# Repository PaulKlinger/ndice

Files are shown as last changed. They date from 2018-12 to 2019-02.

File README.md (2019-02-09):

# Compact Universal Electronic Dice

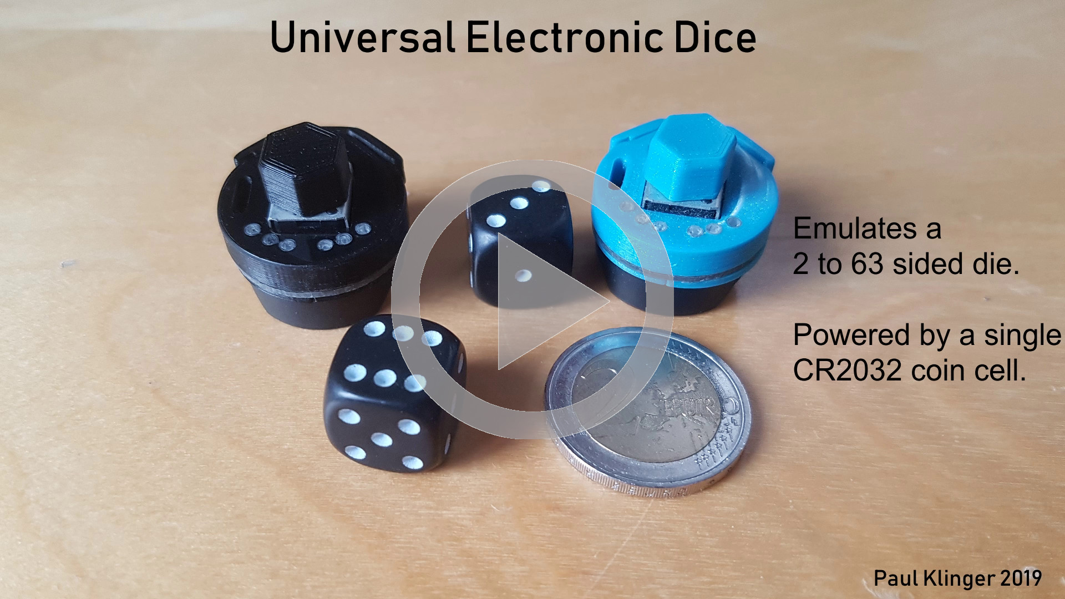
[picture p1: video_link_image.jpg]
(https://youtu.be/G88BLo7Vowo "Project video")


Some hints for anyone trying to build these:

- The PCB should be 0.8mm thick.

- You might have noticed that the two parts of the 3D printed top part that press on the buttons are not symmetric. That's because the smd buttons have a little play on when put into the alignment holes in the PCB (I think the holes on my boards were drilled slightly oversized). I happened to solder the left button a little further in than the right one, and designed the case around that (very professional, I know...).

- The holes over the LEDs in the top cover are filled with some 2mm PMMA fiber optic cable. I bought it [here](https://www.aliexpress.com/item/5mX-Transparent-side-glow-plastic-PMMA-fiber-optic-cable-solid-core-optic-cable-diameter-2mm-3mm/32807597828.html). This kind of fiber is not optimal for this because it glows from the side (which I needed for [this project](https://github.com/PaulKlinger/kerr_geodesic_sculpture)), but most of the light still comes out the end. Getting the fiber into the holes can be kind of tricky, depending on the precise over-/underextrusion of your 3D printer & filament (for me it was a lot easier with the blue than the black ones). I cut the tip of the fiber to a point, push it firmly through so a bit sticks out the other side, and then use pliers to pull it all the way through. Then I cut it flush using some flush cutters. The pliers and cutters invariable leave some scratches so I have to polish the top...

- To get the (3D printed) cap on the potentiometer you need to cut off the top of the knob. The ones mentioned in the BOM have a relatively soft plastic knob, so that's pretty easy. The cap should be a friction fit.

- The battery holder is soldered to the bottom, so that the MCU sits between the bottom of the battery holder and the PCB (the pins should be long enough to still reach through the PCB). Make sure that the battery holder is parallel to the PCB.

- The 3D printed spacers go between the battery holder and the PCB. I glued them to the PCB with superglue. They are mostly there to hide the gap and don't really provide mechanical support.

- The 3D printed top sort of holds in place without glue, but to make sure it sticks I superglued it to the side of the potentiometer by pressing it forward (towards the buttons) and down. This way it can still be removed by pressing in the opposite direction to break the glue.

- The oval hole on the left side of the top cover is used to reprogram the MCU without dissasembling the die. I use a small jig with three spring loaded pogo pins ([bought here](https://www.aliexpress.com/item/50pcs-set-New-P75-B1-Dia-1-02mm-100g-Cusp-Spear-Spring-Loaded-Test-Probes-Pogo/32767984398.html)) to connect to the pads underneath (you need to put some solder in the three holes to make a surface for the pins to push against). The holes are the standard pin header ones, 0.1 inch apart, so you can just solder the pogo pins into three adjacent holes of a protoboard. From the buttons down the three pads are VCC, UPDI data, GND. Here's [a picture](programming_jig.jpg) of the programming jig with a PICkit 4 connected (the PICkit doesn't provide power, so that comes from the usb). (I don't really recommend the pickit, the AVR support is still in beta and there are some irritating bugs.)

I bought all the components except the [ATtiny1614 microcontroller](https://octopart.com/attiny1614-ssfr-microchip-82181131) from Aliexpress. They are, e.g., available here (no guarantee that the links still work):
- [Capacitors (x100) - $1.94](https://www.aliexpress.com/item/100pcs-3-3PF-47UF-0805-SMD-100V-X7R-10-100nf-0-1uf-104K-104-22UF-4/32882102243.html)
- [Resistors (x100) - $0.63](https://www.aliexpress.com/item/100Pcs-0805-SMD-1-4W-0R-10M-chip-resistor-0-10R-100R-220R-330R-470R-1K/32858225842.html)
- [Potentiometers (x10) - $1.41](https://www.aliexpress.com/item/10pcs-x-RV09-vertical-12-5mm-Shaft-5K-10K-50K-100K-0932-Adjustable-Resistor-9-type/32897258726.html)
- [Battery holder (x10) - $0.65](https://www.aliexpress.com/item/10PCS-Battery-Button-Cell-Holder-Socket-Case-CR2032-battery-holder-2032/32819924096.html)
- [LEDs (x100) - $0.55](https://www.aliexpress.com/item/Free-Ship-100PCS-0805-light-emitting-diode-SMD-LED-bead-Red-Yellow-Green-White-Blue-Orange/32871959868.html)
- [switch (x100) - $1.43](https://www.aliexpress.com/item/50pcs-3-6mm-SMD-light-touch-switch-2-pin-side-button-Micro-switch-button-switches-3mm/32311331185.html)

(everything including shipping to Austria)

That's < $0.9 / unit for everything except the microcontroller when building 10 units, and < $1.55 / unit total. (And you have a lot of components left over after building 10, like 80 switches, 40 LEDs, 90 capacitors,...)

If the links above don't work, or you want to buy from more reputable suppliers, check the [octopart bom](pcb/octopart_bom.md).

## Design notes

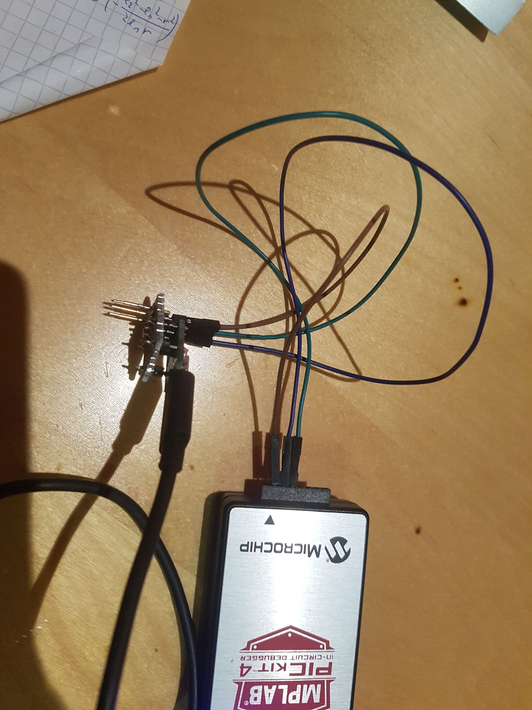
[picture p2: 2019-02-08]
programming_jig.jpg

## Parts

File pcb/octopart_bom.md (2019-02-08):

Qty | Line Item | Manufacturer | MPN | Octopart URL | Schematic Reference | Internal Part Number | Description | Total Qty (@ Batch Size: 1) | SKU | SKU | Packaging | Packaging | Unit Price (@ Batch Size: 1) | Unit Price (@ Batch Size: 1) | In Stock | In Stock | MOQ | MOQ | URL | URL | Distributor [Lowest Price (Overall)] | SKU [Lowest Price (Overall)] | Packaging [Lowest Price (Overall)] | Unit Price (@ Batch Size: 1) [Lowest Price   (Overall)] | Line Total [Lowest Price (Overall)] | Batch Total [Lowest Price (Overall)] | In Stock [Lowest Price (Overall)] | MOQ [Lowest Price (Overall)] | URL [Lowest Price (Overall)] | Notes
-- | -- | -- | -- | -- | -- | -- | -- | -- | -- | -- | -- | -- | -- | -- | -- | -- | -- | -- | -- | -- | -- | -- | -- | -- | -- | -- | -- | -- | -- | --
  |   |   |   |   |   |   |   |   | Digi-Key | Mouser | Digi-Key | Mouser | Digi-Key | Mouser | Digi-Key | Mouser | Digi-Key | Mouser | Digi-Key | Mouser |   |   |   |   |   |   |   |   |   |  
1 | ATTINY1614-SSFR | Microchip | ATTINY1614-SSFR | https://octopart.com/attiny1614-ssfr-microchip-82181131 | 1 | ATTINY1614-SSFRCT-ND | ATTINY1614-SSFR | Cut Tape | 0.75 | 0.75 | 4187 | 4507 | 1 | 1 | https://octopart.com/click/track?ak=39ac400e&sig=0a83d4a&sid=459&ppid=82181131&vpid=431492422&ct=offers | https://octopart.com/click/track?ak=39ac400e&sig=014fdb8&sid=2401&ppid=82181131&vpid=447257214&ct=offers | Arrow Electronics, Inc. | ATTINY1614-SSFR | Cut Tape | 0.7314 | 0.7314 | 0.7314 | 2771 | 1 | https://octopart.com/click/track?ak=39ac400e&sig=05768f2&sid=1106&ppid=82181131&vpid=473294420&ct=offers
1 | GRM21BR61C106KE15L | Murata | GRM21BR61C106KE15L | https://octopart.com/grm21br61c106ke15l-murata-197438 | 1 | 490-3886-1-ND | GRM21BR61C106KE15L | Cut Tape | 0.32 | 0.36 | 5E+06 | 1E+06 | 1 | 1 | https://octopart.com/click/track?ak=39ac400e&sig=0d5de69&sid=459&ppid=197438&vpid=1827596&ct=offers | https://octopart.com/click/track?ak=39ac400e&sig=0187e19&sid=2401&ppid=197438&vpid=38925211&ct=offers | Conrad | 450891 |   | 0.1585 | 0.1585 | 0.1585 | 3263 |   | https://octopart.com/click/track?ak=39ac400e&sig=0ed9acd&sid=14587&ppid=197438&vpid=410932726&ct=offers
1 | A18081100UX0281 | Unique Bargains | A18081100UX0281 | https://octopart.com/a18081100ux0281-unique+bargains-97182774 | 1 |   |   |   |   |   |   |   |   |   |   |   |   | Newegg Business | 9SIV0KK8DW7406 | 5.93 | 5.93 | 5.93 | -2 |   | https://octopart.com/click/track?ak=39ac400e&sig=07dd695&sid=27355&ppid=97182774&vpid=510745618&ct=offers
1 | PTV09A-4020F-B103 | Bourns | PTV09A-4020F-B103 | https://octopart.com/ptv09a-4020f-b103-bourns-1677656 | 1 | PTV09A-4020F-B103-ND | PTV09A-4020F-B103 | Tray | Bulk | 0.83 | 0.74 | 1329 | 815 | 1 | 1 | https://octopart.com/click/track?ak=39ac400e&sig=0dda3a8&sid=459&ppid=1677656&vpid=54316735&ct=offers | https://octopart.com/click/track?ak=39ac400e&sig=0e6202d&sid=2401&ppid=1677656&vpid=37823497&ct=offers | Newark | 10C0389 | 0.666 | 0.666 | 0.666 | 311 | 1 | https://octopart.com/click/track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
6 | KP-2012SYC | Kingbright | KP-2012SYC | https://octopart.com/kp-2012syc-kingbright-7381223 | 6 |   |   |   |   |   |   |   |   |   |   |   |   | TME | KP-2012SYC | 0.1305 | 0.7828 | 0.7828 | 16545 | 5 | https://octopart.com/click/track?ak=39ac400e&sig=0e786ef&sid=1532&ppid=7381223&vpid=88625567&ct=offers
6 | CR0805-JW-103ELF | Bourns | CR0805-JW-103ELF | https://octopart.com/cr0805-jw-103elf-bourns-975882 | 6 | CR0805-JW-103ELFCT-ND | CR0805-JW-103ELF | Cut Tape | 0.1 | 0.1 | 352715 | 0 | 1 | 1 | https://octopart.com/click/track?ak=39ac400e&sig=0185210&sid=459&ppid=975882&vpid=54325049&ct=offers | https://octopart.com/click/track?c=1&ak=39ac400e&sig=01cc0e2&sid=2401&ppid=975882&vpid=37710188&ct=offers | Avnet | 02J2519 | 0.006 | 0.036 | 0.036 | 0 | 1 | https://octopart.com/click/track?c=1&ak=39ac400e&sig=0721438&sid=5822&ppid=975882&vpid=503034749&ct=offers
1 | BS-7 | Memory Protection Devices | BS-7 | https://octopart.com/bs-7-memory+protection+devices-29784142 | 1 | BS-7-ND | Bulk |   | 0.75 |   | 23822 |   | 1 |   | https://octopart.com/click/track?ak=39ac400e&sig=0f913ab&sid=459&ppid=29784142&vpid=1941628&ct=offers | Onlinecomponents.com | BS-7 |   | 0.73 | 0.73 | 0.73 | 1361 | 1 | https://octopart.com/click/track?ak=39ac400e&sig=0dbb6e0&sid=2429&ppid=29784142&vpid=446090856&ct=offers

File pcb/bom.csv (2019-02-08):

Manufacturer Part Number | Description | Quantity | Purchase Link (example)
ATTINY1614-SSFR | MCU | 1 | https://octopart.com/attiny1614-ssfr-microchip-82181131
K2-1112SA-A4SW-01 | smd side switch | 2 | https://www.aliexpress.com/item/50pcs-3-6mm-SMD-light-touch-switch-2-pin-side-button-Micro-switch-button-switches-3mm/32311331185.html
 | 0805 10K smd resistor | 6 | https://www.aliexpress.com/item/100Pcs-0805-SMD-1-4W-0R-10M-chip-resistor-0-10R-100R-220R-330R-470R-1K/32858225842.html
 | 0805 10uf smd ceramic cap | 1 | https://www.aliexpress.com/item/100pcs-3-3PF-47UF-0805-SMD-100V-X7R-10-100nf-0-1uf-104K-104-22UF-4/32882102243.html
 | 0805 yellow smd LED | 6 | https://www.aliexpress.com/item/Free-Ship-100PCS-0805-light-emitting-diode-SMD-LED-bead-Red-Yellow-Green-White-Blue-Orange/32871959868.html
RV09 B100K B104 | 100K potentiometer 12.5mm through hole | 1 | https://www.aliexpress.com/item/10pcs-x-RV09-vertical-12-5mm-Shaft-5K-10K-50K-100K-0932-Adjustable-Resistor-9-type/32897258726.html
 | CR2032 battery holder | 1 | https://www.aliexpress.com/item/10PCS-Battery-Button-Cell-Holder-Socket-Case-CR2032-battery-holder-2032/32819924096.html

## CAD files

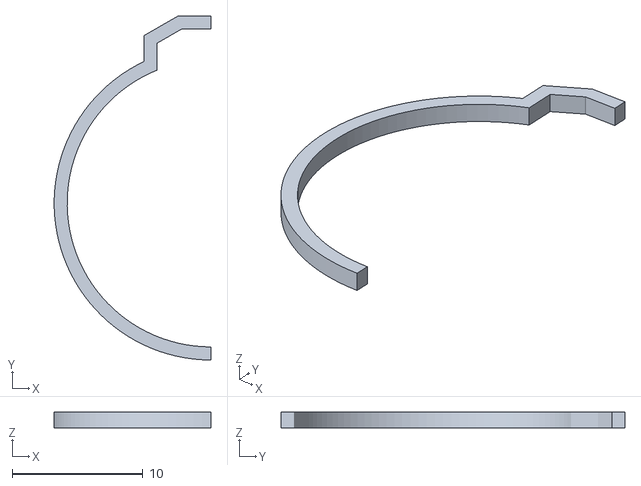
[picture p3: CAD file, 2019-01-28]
3d printed parts/spacer1.stl
12.0 x 26.3 x 1.20

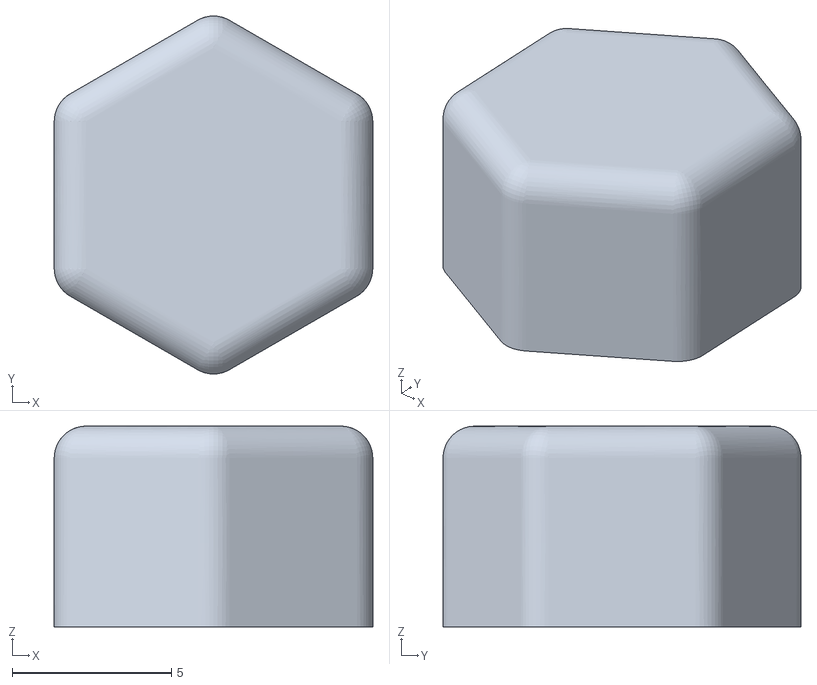
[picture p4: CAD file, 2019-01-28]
3d printed parts/knob.stl
10.0 x 11.2 x 6.30

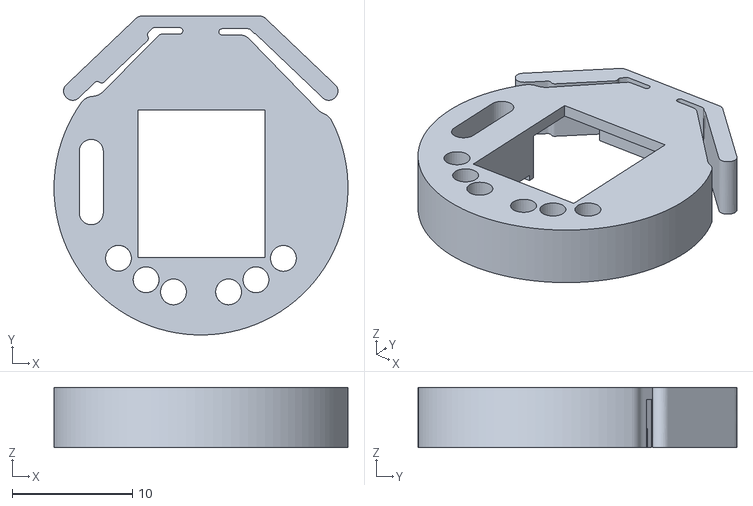
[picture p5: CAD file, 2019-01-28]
3d printed parts/top.stl
24.4 x 26.5 x 5.00

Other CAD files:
3d printed parts/spacer2.stl
3d printed parts/fusion_design.f3d

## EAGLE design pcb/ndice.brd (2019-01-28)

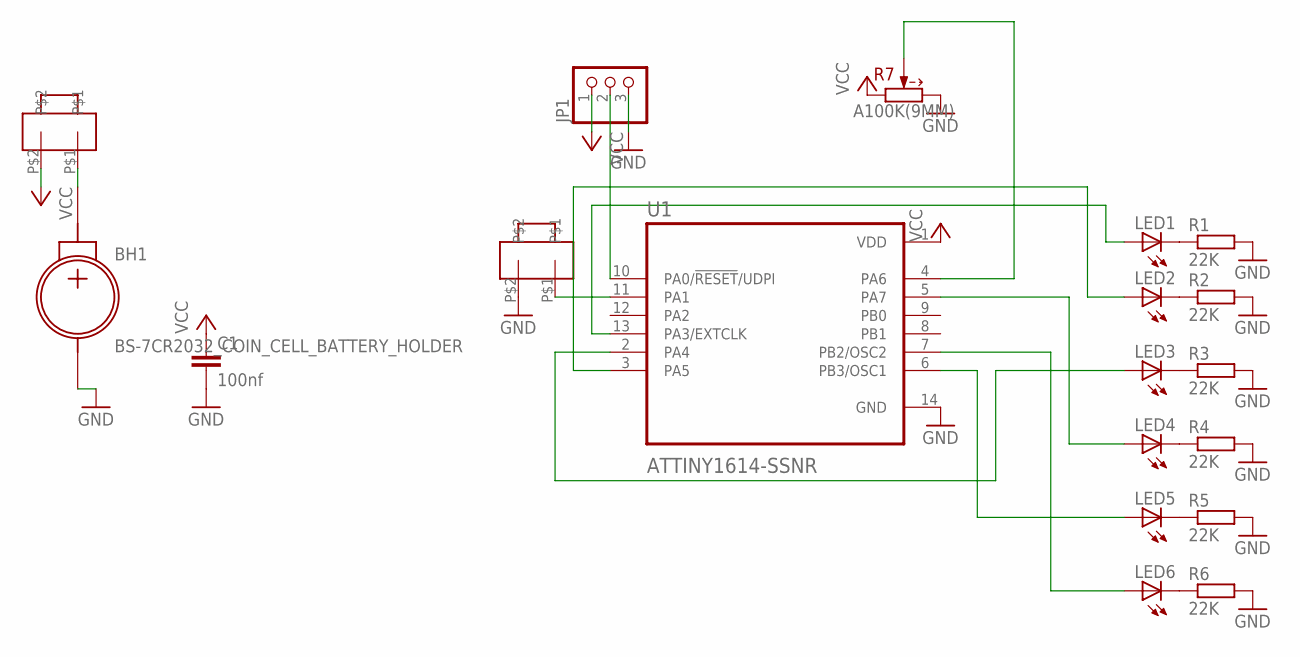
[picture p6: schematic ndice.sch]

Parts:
BH1: BS-7CR2032_COIN_CELL_BATTERY_HOLDER; BS-7
C1: 100nf; C0805
JP1: PINHD-1X3CB; 1X03-CLEANBIG
LED1, LED2, LED3, LED4, LED5, LED6: LEDSML0805; SML0805
R1, R2, R3, R4, R5, R6: 22K; R0805
R7: A100K(9MM); RV09-SINGLE
U1: ATTINY1614-SSNR; SOIC127P600X175-14N
U$1, U$2: SIDEBUTTON; SMD

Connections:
GND: BH1.NEG, C1.2, JP1.3, R1.2, R2.2, R3.2, R4.2, R5.2, R6.2, R7.3 (CW), U1.14 (GND), U$2.P$2
unnamed: BH1.POS, U$1.P$1
unnamed: U1.11 (PA1), U$2.P$1
unnamed: JP1.2, U1.10 (PA0/!RESET!/UDPI)
unnamed: LED1.C, R1.1
unnamed: LED2.C, R2.1
unnamed: LED3.C, R3.1
unnamed: LED4.C, R4.1
unnamed: LED5.C, R5.1
unnamed: LED6.C, R6.1
unnamed: LED1.A, U1.13 (PA3/EXTCLK)
unnamed: LED2.A, U1.3 (PA5)
unnamed: LED3.A, U1.2 (PA4)
unnamed: LED4.A, U1.5 (PA7)
unnamed: LED5.A, U1.6 (PB3/OSC1)
unnamed: LED6.A, U1.7 (PB2/OSC2)
unnamed: R7.2 (W), U1.4 (PA6)
VCC: C1.1, JP1.1, R7.1 (CCW), U1.1 (VDD), U$1.P$2

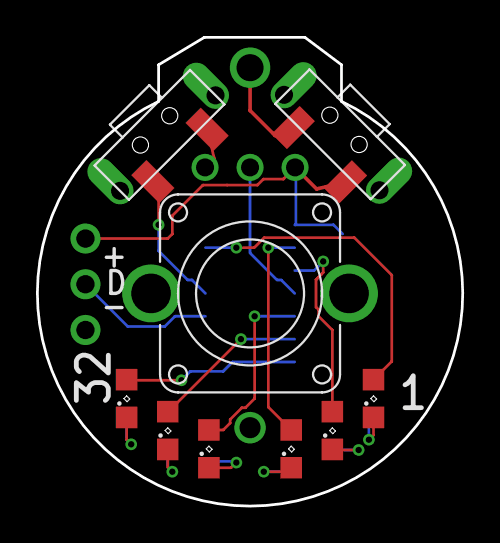
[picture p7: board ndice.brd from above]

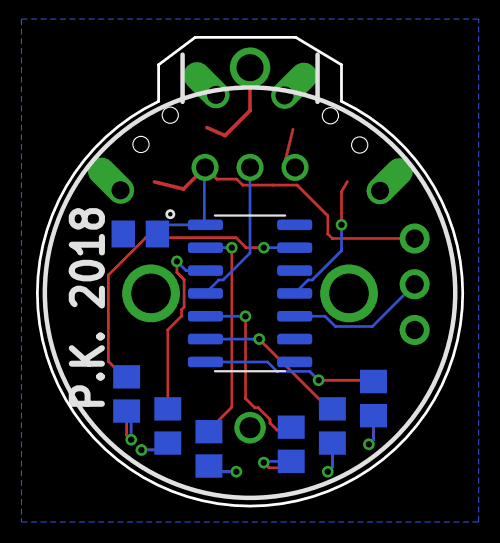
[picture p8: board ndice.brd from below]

Board: 2 copper layers, 23.6 x 26.0 mm, 19 parts (9 on the bottom side), 18 nets.

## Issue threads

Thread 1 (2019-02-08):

BOM needs more info/alternate sources for parts

cmcraft, 2019-02-08:
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

Can we have a more verbose BOM with alternate part numbers or links? I'm trying to build out this project in octopart and I'm having issues sourcing a number of components.

for instance:  K2-1112SA-A4SW-01 is referring to a specific tactile switch that I may be able to source via alibaba but I'm not sure on 0805 10uf smd ceramic cap. What is the voltage on that cap? Does it matter? I apologize if I'm asking dumb questions as this is my first open source hardware project.

PaulKlinger, 2019-02-08:
I don't really have too much information for these parts, I just ordered them off aliexpress, over several years.  You're lucky to get a crappy image with dimensions on there, let alone a part number or datasheet.

The side switch is available [here](https://www.aliexpress.com/item/50pcs-3-6mm-SMD-light-touch-switch-2-pin-side-button-Micro-switch-button-switches-3mm/32311331185.html).

I bought the potentiometers from [here](https://www.aliexpress.com/item/10pcs-x-RV09-vertical-12-5mm-Shaft-5K-10K-50K-100K-0932-Adjustable-Resistor-9-type/32897258726.html). (I don't think I wrote this anywhere but you need to cut off the top of the potentiometer knob to fit the 3d printed cap on it. It's pretty soft plastic, so that's no problem.)

The voltage rating for the capacitor doesn't matter; I don't think there are any that can't handle the 3V from the coin cell. (Anyway, the ATtiny's are pretty tolerant, it would probably work just fine even without the cap.)

[And here's](https://www.aliexpress.com/item/5mX-Transparent-side-glow-plastic-PMMA-fiber-optic-cable-solid-core-optic-cable-diameter-2mm-3mm/32807597828.html) where I bought  the optic fiber that guides the light up from the leds.

Please send me a picture if you build one of these dice, I'd love to see it 😃

cmcraft, 2019-02-08:
Hey Paul!

Thanks for the build notes! This should help out at least a little.

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

PaulKlinger, 2019-02-08:
I've just added a lot more build tips to the [readme](https://github.com/PaulKlinger/ndice/blob/master/README.md) and added the battery holder to the bom.

Sorry that it was so sparse in the beginning, I didn't really think anyone would want to build one ;)

cmcraft, 2019-02-08:
Qty | Line Item | Manufacturer | MPN | Octopart URL | Schematic Reference | Internal Part Number | Description | Total Qty (@ Batch Size: 1) | SKU | SKU | Packaging | Packaging | Unit Price (@ Batch Size: 1) | Unit Price (@ Batch Size: 1) | In Stock | In Stock | MOQ | MOQ | URL | URL | Distributor [Lowest Price (Overall)] | SKU [Lowest Price (Overall)] | Packaging [Lowest Price (Overall)] | Unit Price (@ Batch Size: 1) [Lowest Price   (Overall)] | Line Total [Lowest Price (Overall)] | Batch Total [Lowest Price (Overall)] | In Stock [Lowest Price (Overall)] | MOQ [Lowest Price (Overall)] | URL [Lowest Price (Overall)] | Notes
-- | -- | -- | -- | -- | -- | -- | -- | -- | -- | -- | -- | -- | -- | -- | -- | -- | -- | -- | -- | -- | -- | -- | -- | -- | -- | -- | -- | -- | -- | --
  |   |   |   |   |   |   |   |   | Digi-Key | Mouser | Digi-Key | Mouser | Digi-Key | Mouser | Digi-Key | Mouser | Digi-Key | Mouser | Digi-Key | Mouser |   |   |   |   |   |   |   |   |   |  
1 | ATTINY1614-SSFR | Microchip | ATTINY1614-SSFR | https://octopart.com/attiny1614-ssfr-microchip-82181131 | 1 | ATTINY1614-SSFRCT-ND | ATTINY1614-SSFR | Cut Tape | 0.75 | 0.75 | 4187 | 4507 | 1 | 1 | https://octopart.com/click/track?ak=39ac400e&sig=0a83d4a&sid=459&ppid=82181131&vpid=431492422&ct=offers | https://octopart.com/click/track?ak=39ac400e&sig=014fdb8&sid=2401&ppid=82181131&vpid=447257214&ct=offers | Arrow Electronics, Inc. | ATTINY1614-SSFR | Cut Tape | 0.7314 | 0.7314 | 0.7314 | 2771 | 1 | https://octopart.com/click/track?ak=39ac400e&sig=05768f2&sid=1106&ppid=82181131&vpid=473294420&ct=offers
6 | ERA-6ARW103V | Panasonic | ERA-6ARW103V | https://octopart.com/era-6arw103v-panasonic-20327930 | 6 | P10KBSCT-ND | ERA-6ARW103V | Cut Tape | 0.79 | 0.79 | 41899 | 8617 | 1 | 1 | https://octopart.com/click/track?ak=39ac400e&sig=08efee0&sid=459&ppid=20327930&vpid=88305980&ct=offers | https://octopart.com/click/track?ak=39ac400e&sig=04ccc50&sid=2401&ppid=20327930&vpid=43477964&ct=offers | Newark | 50W0872 | 0.286 | 1.716 | 1.716 | 0 |   | https://octopart.com/click/track?c=1&ak=39ac400e&sig=09ee076&sid=2402&ppid=20327930&vpid=81552968&ct=offers
1 | GRM21BR61C106KE15L | Murata | GRM21BR61C106KE15L | https://octopart.com/grm21br61c106ke15l-murata-197438 | 1 | 490-3886-1-ND | GRM21BR61C106KE15L | Cut Tape | 0.32 | 0.36 | 5E+06 | 1E+06 | 1 | 1 | https://octopart.com/click/track?ak=39ac400e&sig=0d5de69&sid=459&ppid=197438&vpid=1827596&ct=offers | https://octopart.com/click/track?ak=39ac400e&sig=0187e19&sid=2401&ppid=197438&vpid=38925211&ct=offers | Conrad | 450891 |   | 0.1585 | 0.1585 | 0.1585 | 3263 |   | https://octopart.com/click/track?ak=39ac400e&sig=0ed9acd&sid=14587&ppid=197438&vpid=410932726&ct=offers
1 | A18081100UX0281 | Unique Bargains | A18081100UX0281 | https://octopart.com/a18081100ux0281-unique+bargains-97182774 | 1 |   |   |   |   |   |   |   |   |   |   |   |   | Newegg Business | 9SIV0KK8DW7406 | 5.93 | 5.93 | 5.93 | -2 |   | https://octopart.com/click/track?ak=39ac400e&sig=07dd695&sid=27355&ppid=97182774&vpid=510745618&ct=offers
1 | PTV09A-4020F-B103 | Bourns | PTV09A-4020F-B103 | https://octopart.com/ptv09a-4020f-b103-bourns-1677656 | 1 | PTV09A-4020F-B103-ND | PTV09A-4020F-B103 | Tray | Bulk | 0.83 | 0.74 | 1329 | 815 | 1 | 1 | https://octopart.com/click/track?ak=39ac400e&sig=0dda3a8&sid=459&ppid=1677656&vpid=54316735&ct=offers | https://octopart.com/click/track?ak=39ac400e&sig=0e6202d&sid=2401&ppid=1677656&vpid=37823497&ct=offers | Newark | 10C0389 | 0.666 | 0.666 | 0.666 | 311 | 1 | https://octopart.com/click/track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
6 | KP-2012SYC | Kingbright | KP-2012SYC | https://octopart.com/kp-2012syc-kingbright-7381223 | 6 |   |   |   |   |   |   |   |   |   |   |   |   | TME | KP-2012SYC | 0.1305 | 0.7828 | 0.7828 | 16545 | 5 | https://octopart.com/click/track?ak=39ac400e&sig=0e786ef&sid=1532&ppid=7381223&vpid=88625567&ct=offers

Hey Paul! I smashed together a BOM off of octoprint. I had to guess a lot (as parts don't ever match between sites and distributors). This BOM does not include the battery holder. I'll update my test copy accordingly. Does this look anywhere near what you have or will I have an issue somewhere?

cmcraft, 2019-02-08:
https://octopart.com/120591-1-te+connectivity-46505236?r=sp&s=3kDbhNDNT5emb2So2qJi7g

This may match your button cell holder from AliExpress.

PaulKlinger, 2019-02-08:
Looks good, just a few things:
- the potentiometer knob is not round, so you might have to glue the 3d printed cap on (or redesign it)
- these resistors are ludicrously expensive, even on digikey you can get some for ~1/50th the price (e.g. [CR0805-JW-103ELFCT-ND](https://www.digikey.at/product-detail/en/bourns-inc/CR0805-JW-103ELF/CR0805-JW-103ELFCT-ND/3592918))

PaulKlinger, 2019-02-08:
The button cell holders are different, mine have pins that are 20.16mm apart. I'll try to find one than matches on octopart.

cmcraft, 2019-02-08:
Thanks for the catch on those resistors! I just randomly clicked on an entry and didn't check the price.
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
PaulKlinger, 2019-02-08:
Great! I've [added it](https://github.com/PaulKlinger/ndice/blob/master/pcb/octopart_bom.md) to the pcb folder and mentioned it in the readme.
Thanks again :)

cmcraft, 2019-02-08:
No prob! One final question! What did you use to socket the ATTINY1614-SSFR for programming? I have a Teensy 3.2 for the actual programming.

PaulKlinger, 2019-02-08:
Nothing! I program it on the PCB, using the three pads on the left side. I wrote a bit about that in the readme:

> The oval hole on the left side of the top cover is used to reprogram the MCU without dissasembling the die. I use a small jig with three spring loaded pogo pins ([bought here](https://www.aliexpress.com/item/50pcs-set-New-P75-B1-Dia-1-02mm-100g-Cusp-Spear-Spring-Loaded-Test-Probes-Pogo/32767984398.html)) to connect to the pads underneath (you need to put some solder in the three holes to make a surface for the pins to push against). The holes are the standard pin header ones, 0.1 inch apart, so you can just solder the pogo pins into three adjacent holes of a protoboard. From the buttons down the three pads are VCC, UPDI data, GND. Here's [a picture](https://raw.githubusercontent.com/PaulKlinger/ndice/master/programming_jig.jpg) of the programming jig with a PICkit 4 connected (the PICkit doesn't provide power, so that comes from the usb). (I don't really recommend the pickit, the AVR support is still in beta and there are some irritating bugs.)

If you don't want to use pogo pins you can just temporarily solder some wires to that header.

Make sure that your setup can actually program the Attiny1614, it uses the new UPDI interface instead of the old serial one (from e.g. the ATtiny85). (I really like that you only need 3 connections, power, ground, and data now.)

Closed 2019-02-08.

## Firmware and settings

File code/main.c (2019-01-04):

/*
    (c) 2018 Microchip Technology Inc. and its subsidiaries. 
    
    Subject to your compliance with these terms, you may use Microchip software and any 
    derivatives exclusively with Microchip products. It is your responsibility to comply with third party 
    license terms applicable to your use of third party software (including open source software) that 
    may accompany Microchip software.
    
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
    IN NO EVENT WILL MICROCHIP BE LIABLE FOR ANY INDIRECT, SPECIAL, PUNITIVE, 
    INCIDENTAL OR CONSEQUENTIAL LOSS, DAMAGE, COST OR EXPENSE OF ANY KIND 
    WHATSOEVER RELATED TO THE SOFTWARE, HOWEVER CAUSED, EVEN IF MICROCHIP 
    HAS BEEN ADVISED OF THE POSSIBILITY OR THE DAMAGES ARE FORESEEABLE. TO 
    THE FULLEST EXTENT ALLOWED BY LAW, MICROCHIP'S TOTAL LIABILITY ON ALL 
    CLAIMS IN ANY WAY RELATED TO THIS SOFTWARE WILL NOT EXCEED THE AMOUNT 
    OF FEES, IF ANY, THAT YOU HAVE PAID DIRECTLY TO MICROCHIP FOR THIS 
    SOFTWARE.
*/

#include "mcc_generated_files/mcc.h"
#include "mcc_generated_files/include/pin_manager.h"
#include "mcc_generated_files/config/clock_config.h" // why is this not automatic??
#include <util/delay.h>
#include <avr/io.h>

// Note: When generating configuration from MCC sometimes the pullup for PA1
// will not be enabled even though it is set correctly in MCC. Check 
// mcc_generated_files/src/pin_manager.c and either change manually or run
// generate again.


// WARNING!!! I changed "*link_data_start" in
//E:\Program Files (x86)\Microchip\MPLABX\v5.10\packs\Atmel\ATtiny_DFP\1.3.238\gcc\dev\attiny1614\device-specs\specs-attiny1614
// from "-Tdata 0x803800" to "	-Tdata 0x802000"
// this prevents a linker error for static or global variables.
// But I'm very uncertain if this is actually correct.

#define bit_get(p,m) ((p) & (m))
#define bit_set(p,m) ((p) |= (m))
#define bit_clear(p,m) ((p) &= ~(m))
#define bit_flip(p,m) ((p) ^= (m))
#define bit_write(c,p,m) (c ? bit_set(p,m) : bit_clear(p,m))
#define BIT(x) (0x01 << (x))


void show_num(uint8_t num) {
    IO_PA3_set_level(bit_get(num, BIT(0)));
    IO_PA5_set_level(bit_get(num, BIT(1)));
    IO_PA4_set_level(bit_get(num, BIT(2)));
    IO_PA7_set_level(bit_get(num, BIT(3)));
    IO_PB3_set_level(bit_get(num, BIT(4)));
    IO_PB2_set_level(bit_get(num, BIT(5)));
}

/*
    Main application
*/
int main(void)
{
    /* Initializes MCU, drivers and middleware */
    SYSTEM_Initialize();
    
    uint8_t num_sides = 0;
    uint8_t roll = 0;
    /* Replace with your application code */
    while (1){
        if (!IO_PA1_get_level()){
			while (1){
				while (!IO_PA1_get_level()) {
                    /* doing this with random() instead of rand() is much more
                     * accurate, not worth it to use a better algorithm to get
                     * the absolutely correct distribution */
                    roll = 1 + random() % num_sides;
					show_num(roll);
					_delay_ms(10);
				}
				_delay_ms(20);
			}
		}
        ADC0.COMMAND = 1; // start ADC conversion
        while (ADC0.COMMAND); // wait until done
        num_sides = ADC0.RESL / 4;
        
        /* A die with 0 or 1 side is useless, so use these values to make
         * it easier to select the common values 2 and 6 */
        if (num_sides < 6) {num_sides++;}
        if (num_sides < 2) {num_sides++;}
        show_num(num_sides);
        _delay_ms(20);
    }
}
/**
    End of File
*/

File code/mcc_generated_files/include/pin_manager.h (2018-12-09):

/*
    (c) 2018 Microchip Technology Inc. and its subsidiaries. 
    
    Subject to your compliance with these terms, you may use Microchip software and any 
    derivatives exclusively with Microchip products. It is your responsibility to comply with third party 
    license terms applicable to your use of third party software (including open source software) that 
    may accompany Microchip software.
    
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
    IN NO EVENT WILL MICROCHIP BE LIABLE FOR ANY INDIRECT, SPECIAL, PUNITIVE, 
    INCIDENTAL OR CONSEQUENTIAL LOSS, DAMAGE, COST OR EXPENSE OF ANY KIND 
    WHATSOEVER RELATED TO THE SOFTWARE, HOWEVER CAUSED, EVEN IF MICROCHIP 
    HAS BEEN ADVISED OF THE POSSIBILITY OR THE DAMAGES ARE FORESEEABLE. TO 
    THE FULLEST EXTENT ALLOWED BY LAW, MICROCHIP'S TOTAL LIABILITY ON ALL 
    CLAIMS IN ANY WAY RELATED TO THIS SOFTWARE WILL NOT EXCEED THE AMOUNT 
    OF FEES, IF ANY, THAT YOU HAVE PAID DIRECTLY TO MICROCHIP FOR THIS 
    SOFTWARE.
*/
#ifndef PINS_H_INCLUDED
#define PINS_H_INCLUDED

#include "port.h"
/**
 * \brief Set IO_PB3 pull mode
 *
 * Configure pin to pull up, down or disable pull mode, supported pull
 * modes are defined by device used
 *
 * \param[in] pull_mode Pin pull mode
 */
static inline void IO_PB3_set_pull_mode(const enum port_pull_mode pull_mode)
{
	PORTB_set_pin_pull_mode(3, pull_mode);
}

/**
 * \brief Set IO_PB3 data direction
 *
 * Select if the pin data direction is input, output or disabled.
 * If disabled state is not possible, this function throws an assert.
 *
 * \param[in] direction PORT_DIR_IN  = Data direction in
 *                      PORT_DIR_OUT = Data direction out
 *                      PORT_DIR_OFF = Disables the pin
 *                      (low power state)
 */
static inline void IO_PB3_set_dir(const enum port_dir dir)
{
	PORTB_set_pin_dir(3, dir);
}

/**
 * \brief Set IO_PB3 input/sense configuration
 *
 * Enable/disable IO_PB3 digital input buffer and pin change interrupt,
 * select pin interrupt edge/level sensing mode
 *
 * \param[in] isc PORT_ISC_INTDISABLE_gc    = Interrupt disabled but input buffer enabled
 *                PORT_ISC_BOTHEDGES_gc     = Sense Both Edges
 *                PORT_ISC_RISING_gc        = Sense Rising Edge
 *                PORT_ISC_FALLING_gc       = Sense Falling Edge
 *                PORT_ISC_INPUT_DISABLE_gc = Digital Input Buffer disabled
 *                PORT_ISC_LEVEL_gc         = Sense low Level
 */
static inline void IO_PB3_set_isc(const PORT_ISC_t isc)
{
	PORTB_pin_set_isc(3, isc);
}

/**
 * \brief Set IO_PB3 inverted mode
 *
 * Enable or disable inverted I/O on a pin
 *
 * \param[in] inverted true  = I/O on IO_PB3 is inverted
 *                     false = I/O on IO_PB3 is not inverted
 */
static inline void IO_PB3_set_inverted(const bool inverted)
{
	PORTB_pin_set_inverted(3, inverted);
}

/**
 * \brief Set IO_PB3 level
 *
 * Sets output level on a pin
 *
 * \param[in] level true  = Pin level set to "high" state
 *                  false = Pin level set to "low" state
 */
static inline void IO_PB3_set_level(const bool level)
{
	PORTB_set_pin_level(3, level);
}

/**
 * \brief Toggle output level on IO_PB3
 *
 * Toggle the pin level
 */
static inline void IO_PB3_toggle_level()
{
	PORTB_toggle_pin_level(3);
}

/**
 * \brief Get level on IO_PB3
 *
 * Reads the level on a pin
 */
static inline bool IO_PB3_get_level()
{
	return PORTB_get_pin_level(3);
}
/**
 * \brief Set IO_PB2 pull mode
 *
 * Configure pin to pull up, down or disable pull mode, supported pull
 * modes are defined by device used
 *
 * \param[in] pull_mode Pin pull mode
 */
static inline void IO_PB2_set_pull_mode(const enum port_pull_mode pull_mode)
{
	PORTB_set_pin_pull_mode(2, pull_mode);
}

/**
 * \brief Set IO_PB2 data direction
 *
 * Select if the pin data direction is input, output or disabled.
 * If disabled state is not possible, this function throws an assert.
 *
 * \param[in] direction PORT_DIR_IN  = Data direction in
 *                      PORT_DIR_OUT = Data direction out
 *                      PORT_DIR_OFF = Disables the pin
 *                      (low power state)
 */
static inline void IO_PB2_set_dir(const enum port_dir dir)
{
	PORTB_set_pin_dir(2, dir);
}

/**
 * \brief Set IO_PB2 input/sense configuration
 *
 * Enable/disable IO_PB2 digital input buffer and pin change interrupt,
 * select pin interrupt edge/level sensing mode
 *
 * \param[in] isc PORT_ISC_INTDISABLE_gc    = Interrupt disabled but input buffer enabled
 *                PORT_ISC_BOTHEDGES_gc     = Sense Both Edges
 *                PORT_ISC_RISING_gc        = Sense Rising Edge
 *                PORT_ISC_FALLING_gc       = Sense Falling Edge
 *                PORT_ISC_INPUT_DISABLE_gc = Digital Input Buffer disabled
 *                PORT_ISC_LEVEL_gc         = Sense low Level
 */
static inline void IO_PB2_set_isc(const PORT_ISC_t isc)
{
	PORTB_pin_set_isc(2, isc);
}

/**
 * \brief Set IO_PB2 inverted mode
 *
 * Enable or disable inverted I/O on a pin
 *
 * \param[in] inverted true  = I/O on IO_PB2 is inverted
 *                     false = I/O on IO_PB2 is not inverted
 */
static inline void IO_PB2_set_inverted(const bool inverted)
{
	PORTB_pin_set_inverted(2, inverted);
}

/**
 * \brief Set IO_PB2 level
 *
 * Sets output level on a pin
 *
 * \param[in] level true  = Pin level set to "high" state
 *                  false = Pin level set to "low" state
 */
static inline void IO_PB2_set_level(const bool level)
{
	PORTB_set_pin_level(2, level);
}

/**
 * \brief Toggle output level on IO_PB2
 *
 * Toggle the pin level
 */
static inline void IO_PB2_toggle_level()
{
	PORTB_toggle_pin_level(2);
}

/**
 * \brief Get level on IO_PB2
 *
 * Reads the level on a pin
 */
static inline bool IO_PB2_get_level()
{
	return PORTB_get_pin_level(2);
}
/**
 * \brief Set IO_PA1 pull mode
 *
 * Configure pin to pull up, down or disable pull mode, supported pull
 * modes are defined by device used
 *
 * \param[in] pull_mode Pin pull mode
 */
static inline void IO_PA1_set_pull_mode(const enum port_pull_mode pull_mode)
{
	PORTA_set_pin_pull_mode(1, pull_mode);
}

/**
 * \brief Set IO_PA1 data direction
 *
 * Select if the pin data direction is input, output or disabled.
 * If disabled state is not possible, this function throws an assert.
 *
 * \param[in] direction PORT_DIR_IN  = Data direction in
 *                      PORT_DIR_OUT = Data direction out
 *                      PORT_DIR_OFF = Disables the pin
 *                      (low power state)
 */
static inline void IO_PA1_set_dir(const enum port_dir dir)
{
	PORTA_set_pin_dir(1, dir);
}
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

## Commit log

2019-01-02 shift num_sides to make use of otherwise useless ADC values
2019-01-28 added 3d printed parts
    [fusion_design.f3d, knob.stl, spacer1.stl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]
2019-01-28 added pcb files
    [ndice.GBL, ndice.GBO, ndice.GBP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]
2019-01-28 added bom
2019-01-28 renamed bom
    [bom.csv]
2019-01-28 updated gerbers
    [ndice.GBL, ndice.GBO, ndice.GBP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]
2019-01-28 updated eagle brd file
    [ndice.brd]
2019-01-28 ignore gerber files for github language detection
2019-02-08 added purchase links for side buttons and potentiometer
    [bom.csv]
2019-02-08 Added battery holder to bom, build tips to readme
    [bom.csv]
2019-02-08 added purchase links for all the components
    [bom.csv]
2019-02-08 added octopart bom (by https://github.com/cmcraft)
